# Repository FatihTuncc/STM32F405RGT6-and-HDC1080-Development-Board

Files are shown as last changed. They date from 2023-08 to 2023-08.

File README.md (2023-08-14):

# _STM32F405RGT6 and HDC1080 Development Board_

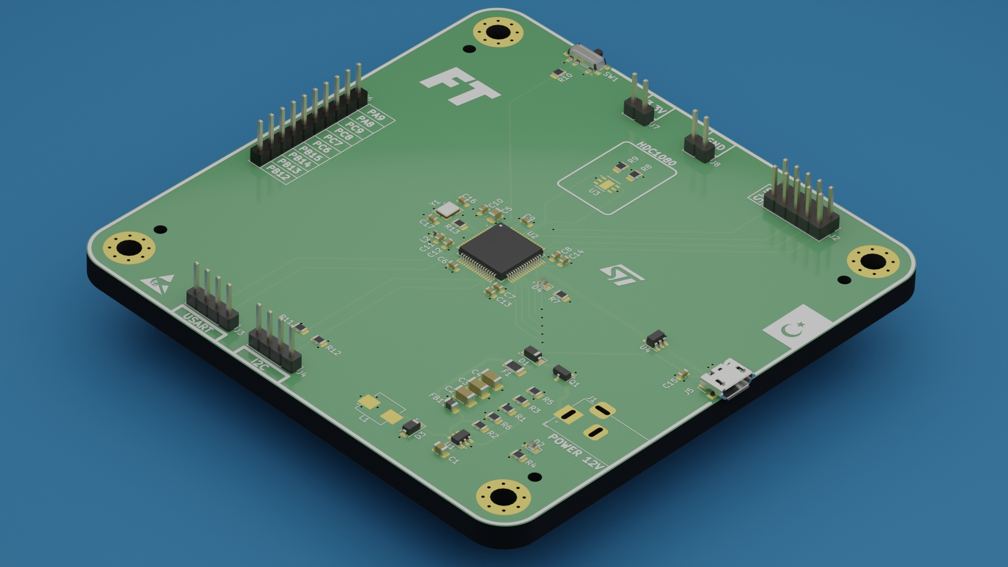
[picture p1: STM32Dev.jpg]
Rendered PCB Image


In this project, a development board was designed using the STM32F405RGT6 processor, HDC1080 sensor and MP2359 step-down IC.
> [!NOTE]
> I rendered the PCB 3D file by transferring it to the Blender program and obtained this realistic image.
## _Components_

- **_STM32F405RGT6:_** The STM32F405RGT6 processor is ideal for high-performance embedded system applications with its 168 MHz processing speed and large memory capacity. I also chose this Microprocessor because it is affordable and new generation.

- **_HDC1080:_** The HDC1080 sensor provides high accuracy for temperature and humidity measurements. It works integrated with STM32F405RGT6 to provide accurate and reliable data. It can communicate with I2C Protocol. There may be alternatives instead of this sensor.

- **_MP2359:_** The MP2359 IC has a wide input voltage range. It saves energy with high efficiency Step-Down regulation. It is a well-known and widely used component.

> [!IMPORTANT]
> I designed the circuit design of these components in accordance with the datasheet. I drew the PCB Designs again in accordance with the Datasheet.

## _Components Recommended For Use (JLCPCB)_

- C13738 Crystal Oscillator
- C221841 Boot switch
- C408412 Power Inductor
- C132560 USB Connector

This information is also available in the BOM file.
## _PCB Image_
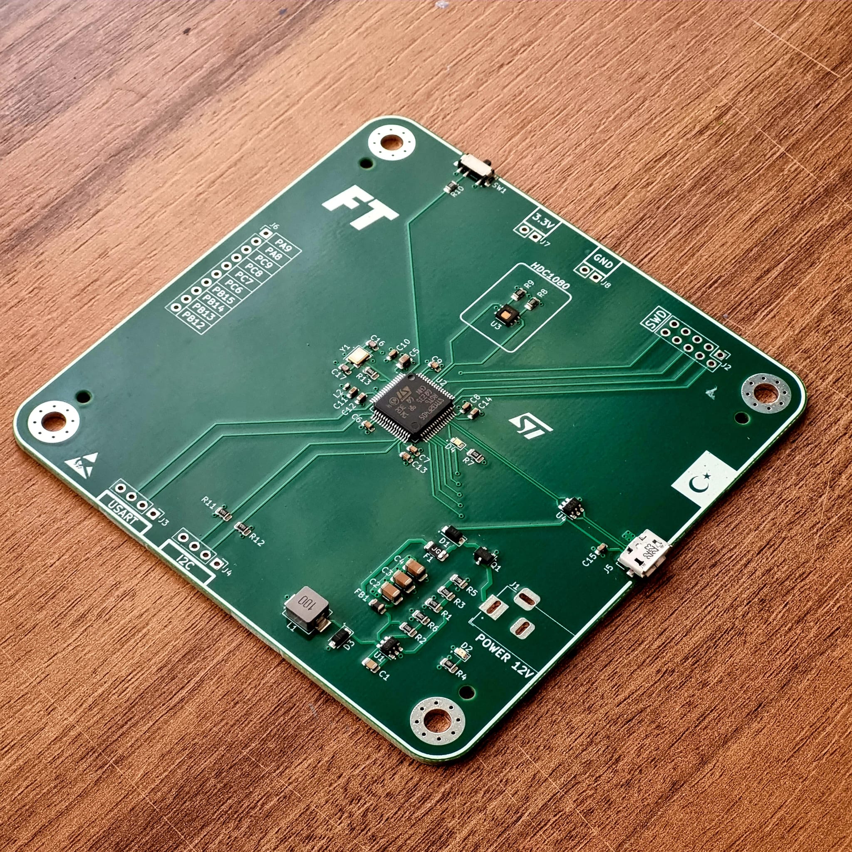
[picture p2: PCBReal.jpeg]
PCB Image


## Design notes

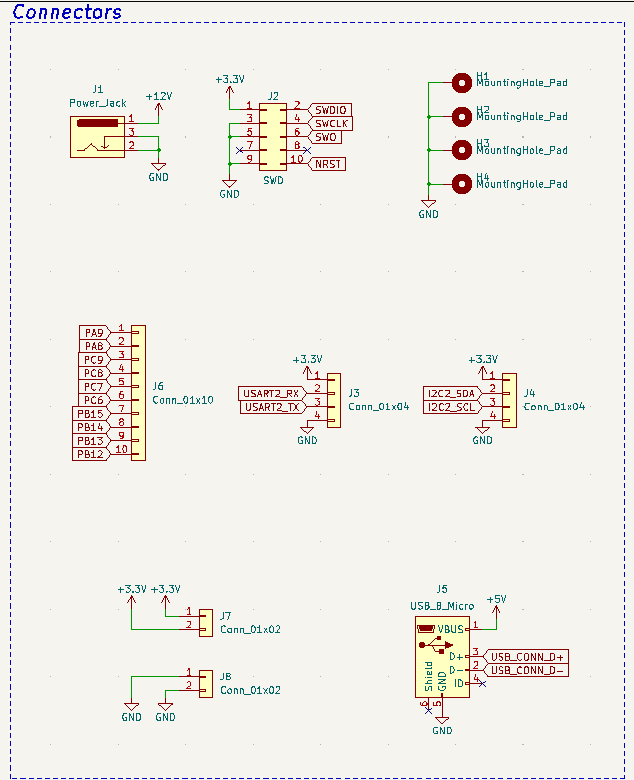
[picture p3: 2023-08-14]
Connectors.png

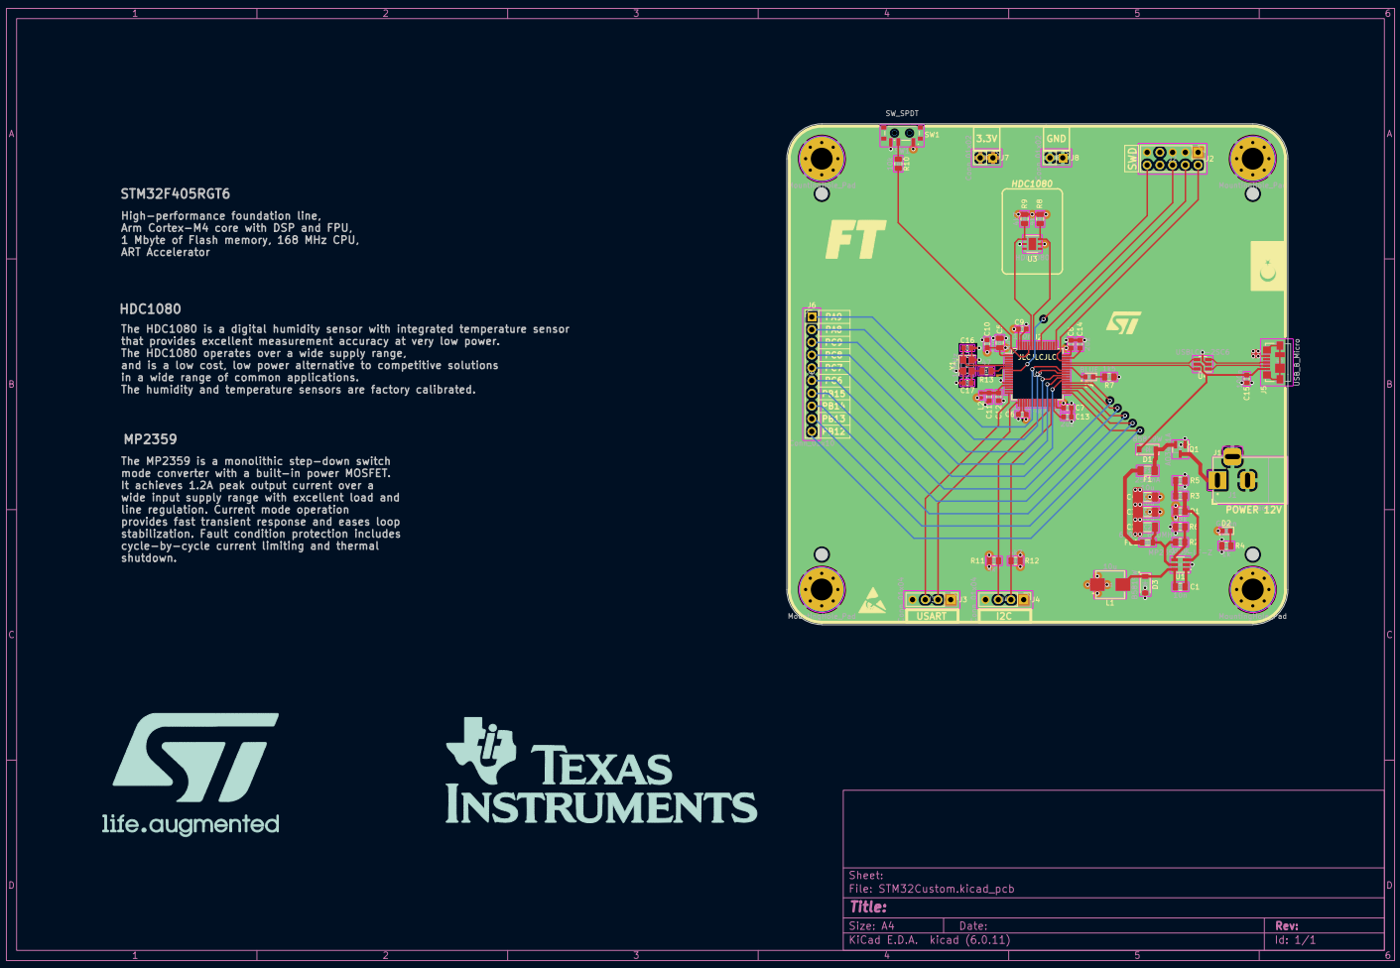
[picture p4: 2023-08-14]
PCB.png

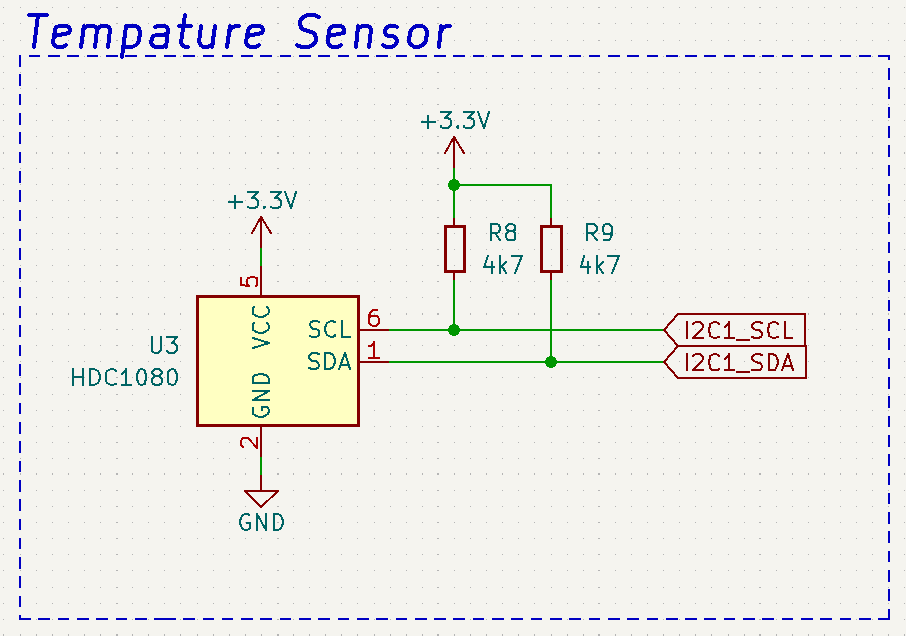
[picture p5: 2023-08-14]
hdc1080.png

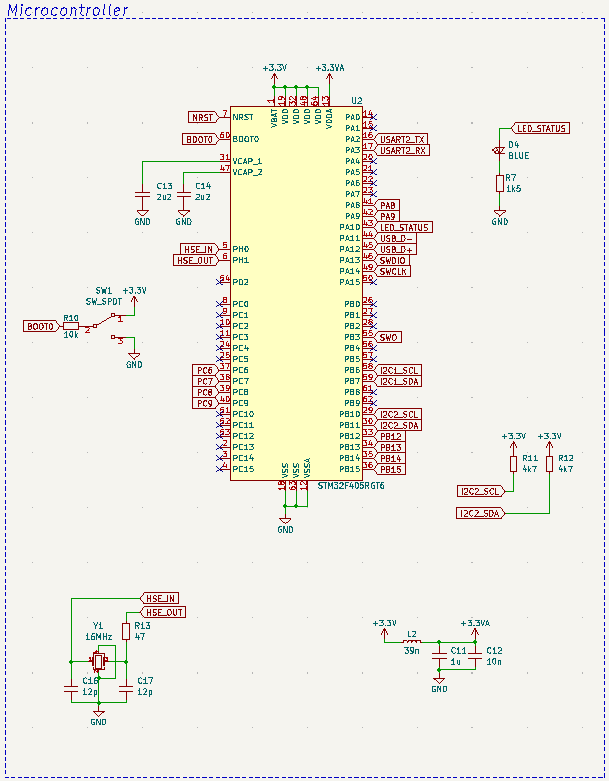
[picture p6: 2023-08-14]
Microcontroller.png

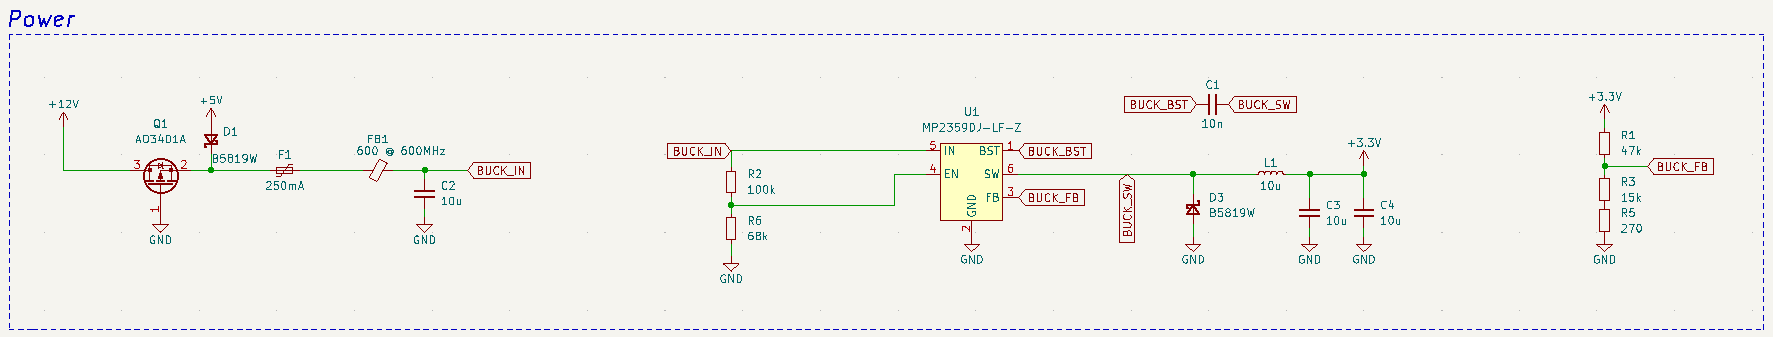
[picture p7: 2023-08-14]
PowerCircuit.png

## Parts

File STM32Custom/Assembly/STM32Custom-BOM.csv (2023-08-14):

Comment | Designator | Footprint | LCSC
10n | C1 | Capacitor_SMD:C_0805_2012Metric | C1710
1u | C11 | Capacitor_SMD:C_0603_1608Metric | C15849
10n | C12 | Capacitor_SMD:C_0603_1608Metric | C57112
2u2 | C13,C14 | Capacitor_SMD:C_0603_1608Metric | C23630
12p | C16,C17 | Capacitor_SMD:C_0603_1608Metric | C38523
10u | C2,C3,C4 | Capacitor_SMD:C_1206_3216Metric | C13585
4u7 | C5 | Capacitor_SMD:C_0805_2012Metric | C1779
100n | C6,C7,C8,C9,C10,C15 | Capacitor_SMD:C_0603_1608Metric | C14663
B5819W | D1,D3 | Diode_SMD:D_SOD-123 | C8598
YELLOW | D2 | LED_SMD:LED_0603_1608Metric | C72038
BLUE | D4 | LED_SMD:LED_0603_1608Metric | C72041
250mA | F1 | Fuse:Fuse_1206_3216Metric | C369159
600 @ 600MHz | FB1 | Inductor_SMD:L_0805_2012Metric | C1017
MountingHole_Pad | H1,H2,H3,H4 | MountingHole:MountingHole_4.3mm_M4_Pad_Via
Power_Jack | J1 | Connector_BarrelJack:BarrelJack_Horizontal
SWD | J2 | Connector_PinHeader_2.54mm:PinHeader_2x05_P2.54mm_Vertical
Conn_01x04 | J3,J4 | Connector_PinHeader_2.54mm:PinHeader_1x04_P2.54mm_Vertical
USB_B_Micro | J5 | Connector_USB:USB_Micro-B_Molex_47346-0001 | C132560
Conn_01x10 | J6 | Connector_PinHeader_2.54mm:PinHeader_1x10_P2.54mm_Vertical
Conn_01x02 | J7,J8 | Connector_PinHeader_2.54mm:PinHeader_1x02_P2.54mm_Vertical
10u | L1 | Inductor_SMD:L_Sunlord_MWSA05xxS | C408412
39n | L2 | Inductor_SMD:L_0402_1005Metric | C26443
AO3401A | Q1 | Package_TO_SOT_SMD:SOT-23 | C15127
47k | R1 | Resistor_SMD:R_0805_2012Metric | C17713
10k | R10 | Resistor_SMD:R_0805_2012Metric | C17414
47 | R13 | Resistor_SMD:R_0805_2012Metric | C17714
100k | R2 | Resistor_SMD:R_0805_2012Metric | C149504
15k | R3 | Resistor_SMD:R_0805_2012Metric | C17475
1k | R4 | Resistor_SMD:R_0805_2012Metric | C17513
270 | R5 | Resistor_SMD:R_0805_2012Metric | C17590
68k | R6 | Resistor_SMD:R_0805_2012Metric | C17801
1k5 | R7 | Resistor_SMD:R_0805_2012Metric | C4310
4k7 | R8,R9,R11,R12 | Resistor_SMD:R_0805_2012Metric | C17673
SW_SPDT | SW1 | Button_Switch_SMD:SW_SPDT_PCM12 | C221841
MP2359DJ-LF-Z | U1 | Package_TO_SOT_SMD:TSOT-23-6 | C2959845
STM32F405RGT6 | U2 | Package_QFP:LQFP-64_10x10mm_P0.5mm | C15742
HDC1080 | U3 | Package_SON:Texas_PWSON-N6 | C82227
USBLC6-2SC6 | U4 | Package_TO_SOT_SMD:SOT-23-6 | C7519
16MHz | Y1 | Crystal:Crystal_SMD_3225-4Pin_3.2x2.5mm | C13738

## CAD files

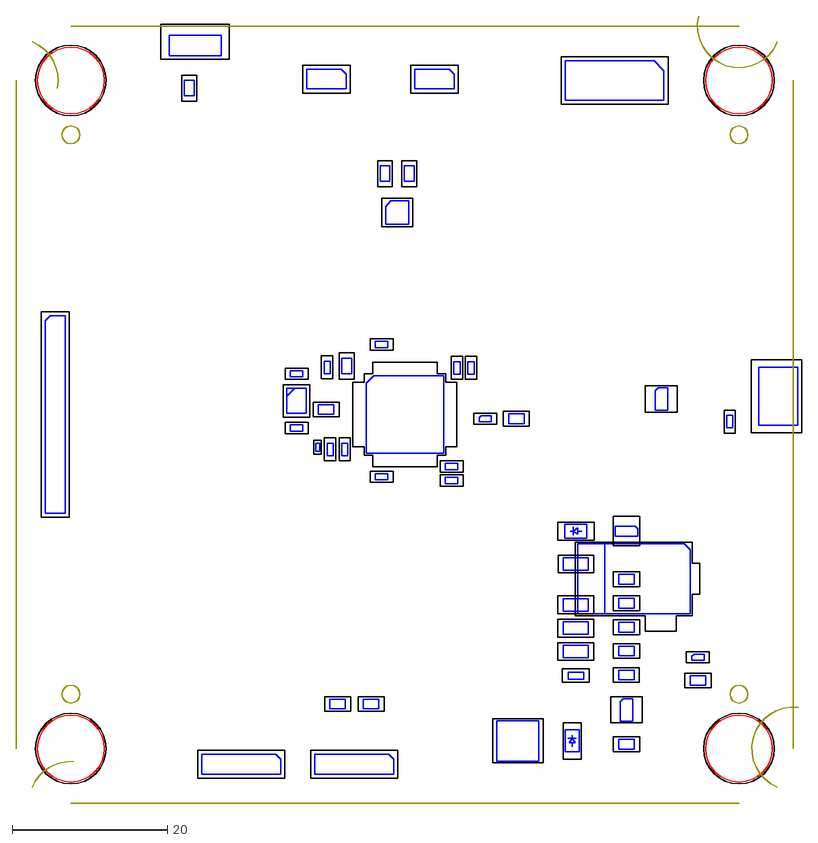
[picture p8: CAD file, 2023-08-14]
STM32Custom/STM32Custom.dxf
101.1 x 101.3

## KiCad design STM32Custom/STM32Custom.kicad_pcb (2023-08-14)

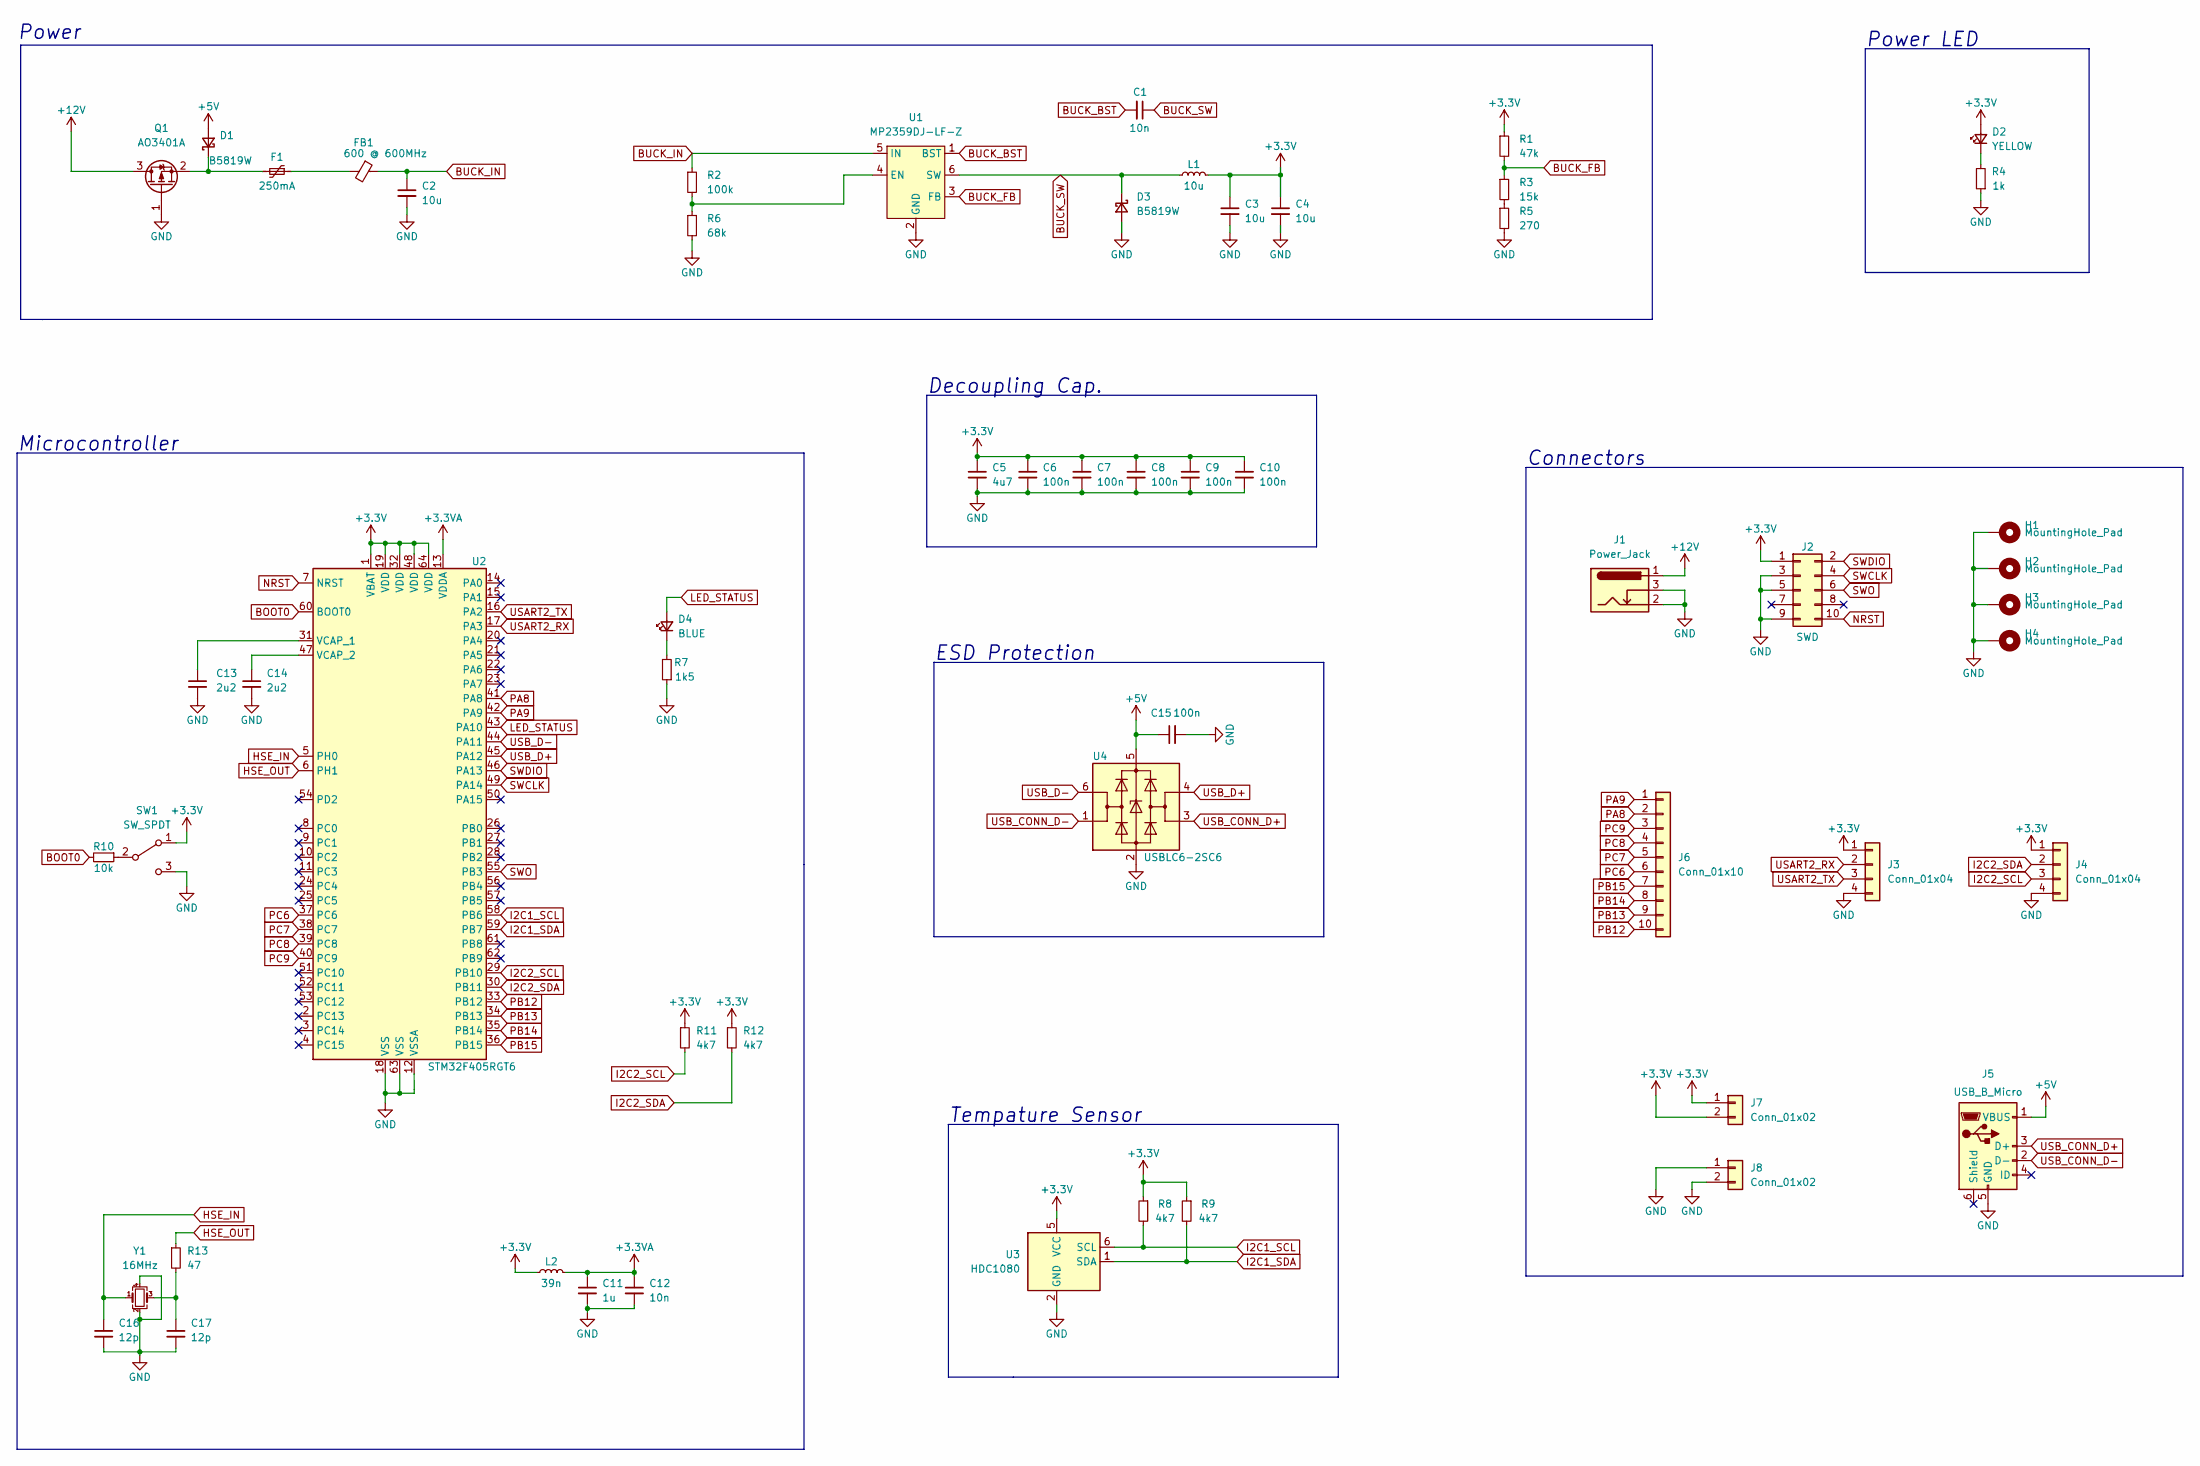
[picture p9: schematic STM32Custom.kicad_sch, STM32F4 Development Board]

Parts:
C1: 10n; C_0805_2012Metric; LCSC Part # C1710
C2, C3, C4: 10u; C_1206_3216Metric; LCSC Part # C13585
C5: 4u7; C_0805_2012Metric; LCSC Part # C1779
C6, C7, C8, C9, C10, C15: 100n; C_0603_1608Metric; LCSC Part # C14663
C11: 1u; C_0603_1608Metric; LCSC Part # C15849
C12: 10n; C_0603_1608Metric; LCSC Part # C57112
C13, C14: 2u2; C_0603_1608Metric; LCSC Part # C23630
C16, C17: 12p; C_0603_1608Metric; LCSC Part # C38523
D1, D3: B5819W; D_SOD-123; LCSC Part # C8598
D2: YELLOW; LED_0603_1608Metric; LCSC Part # C72038
D4: BLUE; LED_0603_1608Metric; LCSC Part # C72041
F1: 250mA; Fuse_1206_3216Metric; LCSC Part # C369159
FB1: 600 @ 600MHz; L_0805_2012Metric; LCSC Part # C1017
H1, H2, H3, H4: MountingHole_Pad; MountingHole_4.3mm_M4_Pad_Via
J1: Power_Jack; BarrelJack_Horizontal
J2: SWD; PinHeader_2x05_P2.54mm_Vertical
J3, J4: Conn_01x04; PinHeader_1x04_P2.54mm_Vertical
J5: USB_B_Micro; USB_Micro-B_Molex_47346-0001; LCSC Part # C132560
J6: Conn_01x10; PinHeader_1x10_P2.54mm_Vertical
J7, J8: Conn_01x02; PinHeader_1x02_P2.54mm_Vertical
L1: 10u; L_Sunlord_MWSA05xxS; LCSC Part # C408412
L2: 39n; L_0402_1005Metric; LCSC Part # C26443
Q1: AO3401A; SOT-23; LCSC Part # C15127
R1: 47k; R_0805_2012Metric; LCSC Part # C17713
R2: 100k; R_0805_2012Metric; LCSC Part # C149504
R3: 15k; R_0805_2012Metric; LCSC Part # C17475
R4: 1k; R_0805_2012Metric; LCSC Part # C17513
R5: 270; R_0805_2012Metric; LCSC Part # C17590
R6: 68k; R_0805_2012Metric; LCSC Part # C17801
R7: 1k5; R_0805_2012Metric; LCSC Part # C4310
R8, R9, R11, R12: 4k7; R_0805_2012Metric; LCSC Part # C17673
R10: 10k; R_0805_2012Metric; LCSC Part # C17414
R13: 47; R_0805_2012Metric; LCSC Part # C17714
SW1: SW_SPDT; SW_SPDT_PCM12; LCSC Part # C221841
U1: MP2359DJ-LF-Z; TSOT-23-6; LCSC Part # C2959845
U2: STM32F405RGT6; LQFP-64_10x10mm_P0.5mm; LCSC Part # C15742
U3: HDC1080; Texas_PWSON-N6; LCSC Part # C82227
U4: USBLC6-2SC6; SOT-23-6; LCSC Part # C7519
Y1: 16MHz; Crystal_SMD_3225-4Pin_3.2x2.5mm; LCSC Part # C13738

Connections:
+3.3VA: C11.1, C12.1, L2.2, U2.13 (VDDA)
+3V3: C3.1, C4.1, C5.1, C6.1, C7.1, C8.1, C9.1, C10.1, D2.2 (A), J2.1, J3.1, J4.1, J7.1, J7.2, L1.2, L2.1, R1.1, R8.1, R9.1, R11.1, R12.1, SW1.1 (A), U2.1 (VBAT), U2.19 (VDD), U2.32 (VDD), U2.48 (VDD), U2.64 (VDD), U3.5 (VCC)
+5V: C15.1, D1.2 (A), J5.1 (VBUS), U4.5 (VBUS)
+12V: J1.1, Q1.3 (D)
BOOT0: R10.2, U2.60 (BOOT0)
BUCK_BST: C1.2, U1.1 (BST)
BUCK_FB: R1.2, R3.1, U1.3 (FB)
BUCK_IN: C2.1, FB1.1, R2.1, U1.5 (IN)
BUCK_SW: C1.1, D3.1 (K), L1.1, U1.6 (SW)
GND: C2.2, C3.2, C4.2, C5.2, C6.2, C7.2, C8.2, C9.2, C10.2, C11.2, C12.2, C13.2, C14.2, C15.2, C16.2, C17.2, D3.2 (A), H1.1, H2.1, H3.1, H4.1, J1.2, J1.3, J2.3, J2.5, J2.9, J3.4, J4.4, J5.5 (GND), J8.1, J8.2, Q1.1 (G), R4.1, R5.2, R6.2, R7.1, SW1.3 (C), U1.2 (GND), U2.12 (VSSA), U2.18 (VSS), U2.63 (VSS), U3.2 (GND), U4.2 (GND), Y1.2, Y1.4
HSE_IN: C16.1, U2.5 (PH0), Y1.1
HSE_OUT: R13.1, U2.6 (PH1)
I2C1_SCL: R8.2, U2.58 (PB6), U3.6 (SCL)
I2C1_SDA: R9.2, U2.59 (PB7), U3.1 (SDA)
I2C2_SCL: J4.3, R11.2, U2.29 (PB10)
I2C2_SDA: J4.2, R12.2, U2.30 (PB11)
LED_STATUS: D4.2 (A), U2.43 (PA10)
NRST: J2.10, U2.7 (NRST)
unnamed: C13.1, U2.31 (VCAP_1)
unnamed: C14.1, U2.47 (VCAP_2)
unnamed: C17.1, R13.2, Y1.3
unnamed: D1.1 (K), F1.2, Q1.2 (S)
unnamed: D2.1 (K), R4.2
unnamed: D4.1 (K), R7.2
unnamed: F1.1, FB1.2
unnamed: R2.2, R6.1, U1.4 (EN)
unnamed: R3.2, R5.1
unnamed: R10.1, SW1.2 (B)
PA8: J6.2, U2.41 (PA8)
PA9: J6.1, U2.42 (PA9)
PB12: J6.10, U2.33 (PB12)
PB13: J6.9, U2.34 (PB13)
PB14: J6.8, U2.35 (PB14)
PB15: J6.7, U2.36 (PB15)
PC6: J6.6, U2.37 (PC6)
PC7: J6.5, U2.38 (PC7)
PC8: J6.4, U2.39 (PC8)
PC9: J6.3, U2.40 (PC9)
SWCLK: J2.4, U2.49 (PA14)
SWDIO: J2.2, U2.46 (PA13)
SWO: J2.6, U2.55 (PB3)
USART2_RX: J3.2, U2.17 (PA3)
USART2_TX: J3.3, U2.16 (PA2)
USB_CONN_D+: J5.3 (D+), U4.3 (I/O2)
USB_CONN_D-: J5.2 (D-), U4.1 (I/O1)
USB_D+: U2.45 (PA12), U4.4 (I/O2)
USB_D-: U2.44 (PA11), U4.6 (I/O1)

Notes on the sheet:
ESD Protection
Tempature Sensor
Connectors
Decoupling Cap.
Power
Power LED
Microcontroller

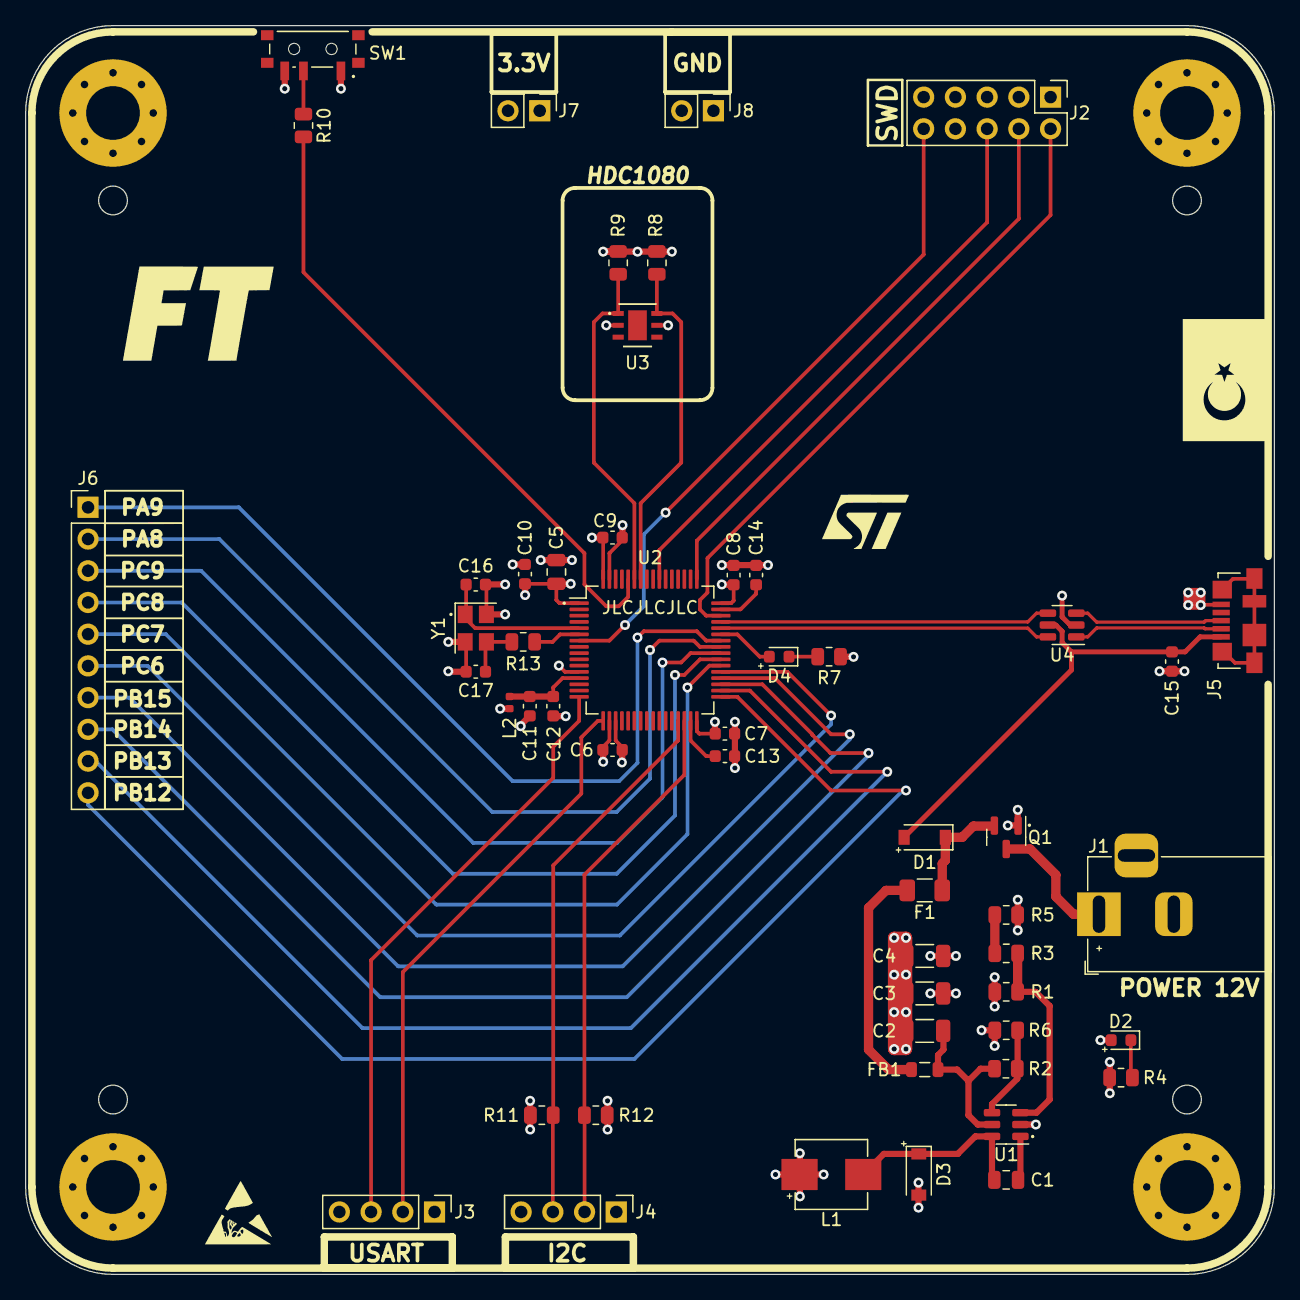
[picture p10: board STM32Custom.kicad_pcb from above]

Board: 4 copper layers, 100.0 x 100.0 mm, 57 parts (0 on the bottom side), 47 nets.

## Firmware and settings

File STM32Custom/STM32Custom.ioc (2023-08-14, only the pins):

Mcu.UserName=STM32F405RGTx
PA10.Signal=GPIO_Output
PA11.Signal=USB_OTG_FS_DM
PA12.Signal=USB_OTG_FS_DP
PA13.Signal=SYS_JTMS-SWDIO
PA14.Signal=SYS_JTCK-SWCLK
PA2.Signal=USART2_TX
PA3.Signal=USART2_RX
PB10.Signal=I2C2_SCL
PB11.Signal=I2C2_SDA
PB3.Signal=SYS_JTDO-SWO
PB6.Signal=I2C1_SCL
PB7.Signal=I2C1_SDA
PH0-OSC_IN.Signal=RCC_OSC_IN
PH1-OSC_OUT.Signal=RCC_OSC_OUT
